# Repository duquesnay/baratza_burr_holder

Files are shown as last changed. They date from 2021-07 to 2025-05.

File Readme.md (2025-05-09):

# Baratza Encore Burr holder 3d model

3d Model for Baratza Encore burr holder - remixed from thingiverse: <https://www.thingiverse.com/thing:1731803>

## Thingiverse

Published based on : 

### Thingiverse Description

Baratza burr holder re-engineered from Michał Barczewski's version on thingiverse: <https://www.thingiverse.com/thing:4900741>

I've made some heavy handed changes
- redesigned some parts to be more fit to 3d printing & PETG, regarding strength overall and precision
- most noticeable are: a full on outer threading instead of small original tabs ; thicker rings on top for easier printing and sturdiness
- added a rugged outside for manual screwing/unscrewing when testing

Model available on: https://github.com/duquesnay/baratza_burr_holder.git

### Print notes
(GD After a bit of trail & error)
- PETG is the way. PLA is too hard and won't handle the friction of the outer threading for a part so thin. Everything is small and put together tight in the grinder so the flexibility is not getting in the way. Also, heat resistance is never bad, grinding creates heat
- 0.2 layer height needed to gives a smooth threading
- 0.43 layers width w 0.6 nozzle
- wall count of 3 w 0.6 nozzle, the part is mostly solid.
- no support: it never comes out clean from the outer thread, any bits add friction
- made to use straigt out of the printer 

## Code style notes
I've made a lot of refactoring from the original code, based on software coding experience
- went hard Clean Code principles to refactor the file: named most hard coded value as variables and modules renamed to express the function of the part. Should be easier to work on
- redesigned the shape hierarchy so each part is visualized independently (different colors)

## Design Notes
Recent updates:
- BOSL2 library integration for advanced features
- Printing upside down 
  - prevents support since the top part of the millstone, main point of pressure on it, is flat
  - had to extend external tabs -now a ring to the max height
- Outer thread
  - Replaced middle tab with thread_helix - smoother & stronger threads
  - Triple-start trapezoidal thread design - easy printing, easy sliding, but precise holding (since thread goes all the way around)
  - Thread params: 0.3 turns, 2mm pitch, 1.5mm depth (max is 2 but not more friction and printing issue, lead-in for easy engagement
- Top part
  - Replaces flimsy top tabs with full rings, going all the way up for support. Nothing else needed
  - There's a flat bridge between the upper rings but it prints easy at this dimension (2mm in circle)
- Bottom
  - cylinder segments is split by sections, to work on each feature independently
  - the tabs retaining the millstone have vertical slit for flexibility, there must be a stronger way, they might need a bit of care... but also do push it strongly 

 ## Todos
- [X] remove pointless cutouts on bottom top shoulder
- [X] remove useless shoulder between top and bottom
- [X] replace top tabs as a full ring for resistance and printing
- [X] thicken the stabiliser ridge to limit movement of the burr
- [X] fine-tuned the spacing between the rings for taking in the rubber part

## License
Attribution-NonCommercial-ShareAlike 4.0 International (CC BY-NC-SA 4.0) <https://creativecommons.org/licenses/by-nc-sa/4.0/>

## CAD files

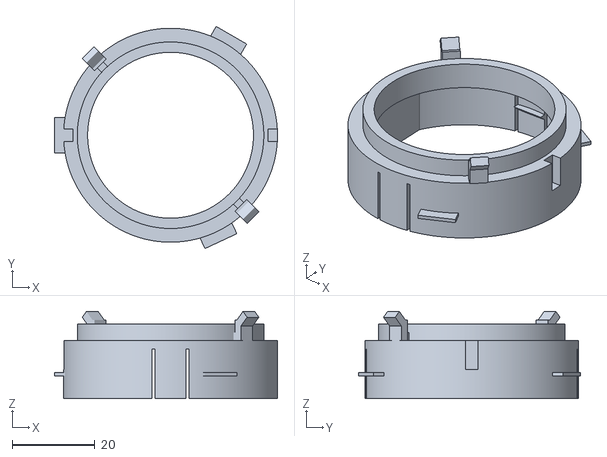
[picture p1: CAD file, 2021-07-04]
burrholder_v3.stl
53.8 x 53.6 x 21.0

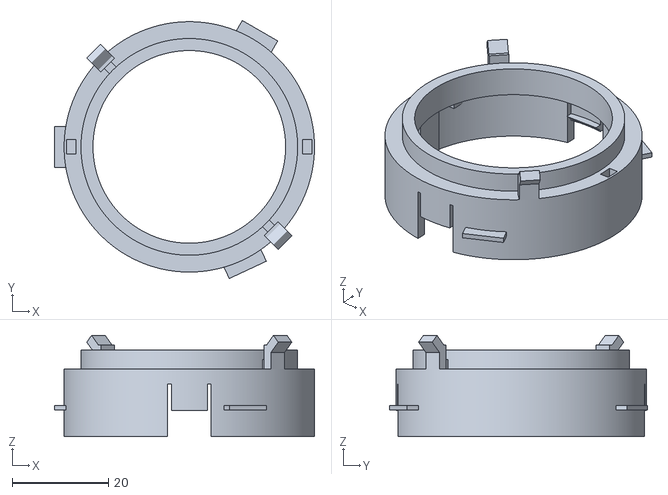
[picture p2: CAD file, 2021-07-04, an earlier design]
burrholder_v2.stl
54.0 x 53.6 x 21.0

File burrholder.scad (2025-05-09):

// Include BOSL2 library
include <BOSL2/std.scad>
include <BOSL2/threading.scad>

// Quality settings
$fa = 0.1;
$fs = 0.4;

// Dimensions - Main structure
outer_diameter = 51.6; // [51:0.05:53]
bottom_radius = outer_diameter / 2;
bottom_thickness = 1.7; // [1:0.1:2]
bottom_internal_radius = bottom_radius - bottom_thickness;


// Parameters for upper ring
top_ring1_outer_radius = 21;
top_ring1_inner_radius = 18;
top_rings_spacing = 2.5;    // Spacing between ring 1 and 2
top_ring2_outer_radius = bottom_radius + 2;


// Parameters for upper tabs
rubber_tab_width = 2;
rubber_tab_height = 3;  // Added to shoulder_height
rubber_tab_angles = [45, 225];  // Angles around the circle where tabs are placed

// Parameters for retainer tabs
retainer_tab_contenance = 4.5; // Millstone has a 4mm lip, so .5 margin

// Heights - Sections
top_rings_height = 5;
shoulder_height = 3;
bottom_height = 11;
shoulder_extension = 1.5;

// Tabs - Dimensions
side_holder_length = 1.2; // [1:0.1:2]

// https://en.wikibooks.org/wiki/OpenSCAD_User_Manual/Primitive_Solids
module prism(l, w, h) {
    polyhedron(
    points = [[0, 0, 0], [l, 0, 0], [l, w, 0], [0, w, 0], [0, w, h], [l, w, h]],
    faces = [[0, 1, 2, 3], [5, 4, 3, 2], [0, 4, 5, 1], [0, 3, 4], [5, 2, 1]]);
}


// Create a beveled cylinder - generic function
// h = height, or = outer radius, ir = inner radius, tb = top bevel width, bb = bottom bevel width
module beveled_tube(h, or, ir, tb = 0, bb = 0) {
    assert(or >= ir, "Inner radius must be less than outer radius");
    assert(h >= tb + bb, str("Height (", h, ") must be greater than top plus bottom bevels", [tb, bb]));
    echo("Beveled tube: ", [h, or, ir, tb, bb]);
    thickness = or - ir;
    if (tb > thickness) {
        tb = thickness;
    }
    if (bb > thickness) {
        bb = thickness;
    }
    union() {
        if (h > bb + tb)
            translate([0, 0, bb])
                tube(h = h - tb - bb, or = or, ir = ir, center = false);
        if (tb > 0)
            translate([0, 0, h - tb])
                tube(h = tb, or1 = or, or2 = or - tb, ir = ir, center = false);
        if (bb > 0) {
            tube(h = bb, or1 = or - bb, or2 = or, ir = ir, center = false);
        }
    }
}

// Stable tube/ring module using only core OpenSCAD functions
// Parameters:
// h = height of the tube
// or1 = outer radius at bottom
// or2 = outer radius at top (defaults to or1 if not specified)
// ir1 = inner radius at bottom
// ir2 = inner radius at top (defaults to ir1 if not specified)
// fn = optional fragment number (resolution)
module stable_tube(h, or1, ir1, or2 = undef, ir2 = undef, fn = $fn) {
    // Default values for optional parameters
    or2_actual = (or2 == undef) ? or1 : or2;
    ir2_actual = (ir2 == undef) ? ir1 : ir2;

    // Input validation
    assert(h > 0, str("Height must be positive: ", h));
    assert(or1 >= ir1, "Outer radius must be greater than inner radius at bottom");
    assert(or2_actual >= ir2_actual, "Outer radius must be greater than inner radius at top");

    // Create a 2D profile and rotate it around the Z axis
    rotate_extrude(angle = 360, $fn = fn) {
        polygon(
        points = [
                [ir1, 0], // Bottom inner
                [or1, 0], // Bottom outer
                [or2_actual, h], // Top outer
                [ir2_actual, h]    // Top inner
            ],
        // Define the face as a simple quad
        paths = [[0, 1, 2, 3]]
        );
    }
}

// Create the hollow top cylinder
module top_ring1(
outer_radius = top_ring1_outer_radius,
inner_radius = top_ring1_inner_radius,
height = top_rings_height
) {
    tube(h = height, or = outer_radius, ir = inner_radius, center = false);
}

// Create a continuous vertical ring around the top cylinder with connectors
module top_ring2(
height = top_rings_height,
base_spacing = top_rings_spacing, // should be refreing to connector origin
outer_radius = top_ring2_outer_radius  // Same as shoulder outer_radius default
) {
    inner_radius = base_spacing + top_ring1_outer_radius;
    thickness = outer_radius - inner_radius;
    outer_radius = outer_radius; // making it thicker to compensate
    bb = outer_radius - bottom_radius; // just in case we decide to over over large

    difference() {

        beveled_tube(
        h = height,
        or = outer_radius,
        ir = inner_radius,
        tb = 0,
        bb = bb
        );

        count = 8;
        for (i = [0:count - 1])
        rotate([0, 0, i * (360 / count)])
            translate([outer_radius + 4, 0, 0])
                cylinder(r = 6, h = height);

    }

}

// Create the shoulder transition part with reinforcement
// @todo to refactor, using common variables, etc
module shoulder(
height = shoulder_height,
inner_radius = top_ring1_inner_radius,
outer_radius = bottom_radius
) {
    bevel = top_rings_spacing;
    tube(h = height, or = outer_radius, ir = inner_radius, center = false);
}

// Parameters for middle tab thread
middle_tab_pitch = 2;
middle_tab_thread_width = 0.8;  // Make thread thinner (1mm in total width)
middle_tab_thread_depth = 2;    // Make thread thinner (1mm in total width)
middle_tab_turns = 0.3;
middle_tab_starts = 3;
middle_tab_lead_in = 2;
middle_tab_left_handed = true;
thread_depth = 1.5;      // Standard depth for reliable threading

// Middle tab with helix angle for threading onto the grinder
module tightening_thread() {
    // Use standard thread parameters that are known to work well

    // Use the default thread profile which renders reliably
    thread_helix(
    turns = middle_tab_turns, // Standard turns value
    d = (bottom_radius) * 2, // Outer diameter
    pitch = 2, // Distance between complete turns, fixed
    starts = 3, // Triple-start thread
    thread_depth = thread_depth, // how deep the thread goes, max 2 probably
//    thread_angle = 0, // Square thread profile for precision fit
    left_handed = true,
    lead_in1 = 2, // Standard lead-in
    anchor = BOTTOM
    );
}

// Create a segment of the hollow bottom cylinder
module bottom_cylinder_segment(
start_angle,
end_angle,
outer_radius = bottom_radius,
inner_radius = bottom_internal_radius,
height
) {
    angle_span = end_angle - start_angle;

    // Outer segment
    rotate([0, 0, start_angle])
        rotate_extrude(angle = angle_span)
            translate([inner_radius, 0, 0])
                square([outer_radius - inner_radius, height]);
}

// Create a holder segment with the millstone holder integrated
module millstone_holder_segment(
angle_width = 60, // Angular width of the segment
outer_radius = bottom_radius,
inner_radius = bottom_internal_radius,
height = bottom_height,
overlap_clearance = 0.05,
height_clearance = 0.1
) {
    // Calculate the start and end angles to center the holder at 0°
    half_width = angle_width / 2;
    start_angle = -half_width;
    end_angle = half_width;

    union() {
        // Create the cylinder segment
        bottom_cylinder_segment(
        start_angle = start_angle,
        end_angle = end_angle,
        outer_radius = outer_radius,
        inner_radius = inner_radius,
        height = height
        );

        millstone_single_holder();
    }
}

// Create a segment with millstone retaining tab and horizontal flexibility slots
module millstone_retainer_tab_segment(
angle_width,
height = bottom_height,
z_position = bottom_height - retainer_tab_contenance,
tab_width = 7.5,
tab_depth = 1.5,
outer_radius = bottom_radius,
inner_radius = bottom_internal_radius,
tab_length = side_holder_length,
slit_width = 1,
) {
    // Calculate the start and end angles to center the tab with a negative margin to create slits
    end_angle = angle_width / 2 - slit_width;
    start_angle = -end_angle;

    union() {
        // Create the complete cylinder segment
        bottom_cylinder_segment(
        start_angle = start_angle,
        end_angle = end_angle,
        height = height
        );

        // Add the millstone tab - rotated to align perpendicular to the cylinder radius
        // The -90° rotation positions the tab at right angles to the segment's central angle
        translate([inner_radius, 0, z_position])
            rotate([0, 0, 180])
                //            translate([ inner_radius, 0, z_position])
                retainer_tab(tab_width, tab_depth, tab_length);
    }
}

// Create a single millstone tab
module retainer_tab(
width,
depth,
height,
) {
    rotate([-90, 0, 0])
        linear_extrude(width, center = true)
            polygon(points = [[0, 0], [depth, 0], [0, height]]);
}
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

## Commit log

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2021-07-04 fix module name in debug
    [burrholder.scad]
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2021-07-04 fix top cutout to account for bigger diameter
    [burrholder.scad]
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2021-07-04 revert side holders
    [burrholder.scad]
2021-07-04 make side holders adjustable and shorten them
    [burrholder.scad]
2025-01-18 top cylinder now as high as the tabs
    [burrholder.scad]
2025-01-18 replacing top slanted tip by a bevel tip for top bed adhesion
    [burrholder.scad]
2025-01-18 refactor top tabs creation: - tab extending to top height to be printed upside down - clean code, more variables, etc
    [burrholder.scad]
2025-01-18 form changed: beveling middle shoulder for easier upside down print (to be tested)
    [burrholder.scad]
2025-01-18 refactored for adjustement - cylinders don't overlap - using bottom, shoulder, top, as reference name - upper tabs go down to the bottom as the shoulder will be tapered - ring stone holder made throu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
    [burrholder.scad]
2025-01-18 refactored for adjustement - stone holders refactored to use functions and parameters in place of hard values
    [burrholder.scad]
2025-01-18 made stone holder tabs tigher by half a millimeter
    [burrholder.scad]
2025-05-02 refactor: extract magic numbers into named variables for improved maintainability
    - Add descriptive variable names across all modules
    - Improve code readability with consistent naming
    - Add helpful comments describing purpose of sections
    - Use overlap_clearance consistently for 3D operations
    [burrholder.scad]
2025-05-02 refactor: standardize naming conventions throughout codebase
    - Use consistent suffix naming (_height, _width, _radius)
    - Rename variables for clarity (tab_mid_h → middle_tab_height)
    - Convert indexed loops to named angle arrays
    - Group related parameters with prefixes (holder_*)
    - Improve organization with section comments
    - Standardize parameter variable names across modules
    [burrholder.scad]
2025-05-02 feat: improve debugging visualization for cutouts
    - Enhance debug visualization to show all cutout types
    - Add colored visualization for retaining tabs (green) and top cutouts (yellow)
    - Extract cutout application into dedicated apply_cutouts module
    - Use array-based loop for slit cutouts rotation
    - Fix variable reference (bottom_h to bottom_height)
    - Add explanatory comments for better maintainability
    [burrholder.scad]
2025-05-02 fix: correct debugging visualization syntax errors
    - Fix typo in millstone_cutouts_slits function name
    - Correct condition check (was comparing to 0 instead of 1)
    - Enable debugging visualization by default
    - Uncomment debugging section
    [burrholder.scad]
2025-05-02 fix: correct all OpenSCAD for-loop syntax
    - Replace all instances of incorrect 'for (x in array)' syntax
    - Use proper OpenSCAD array iteration with indexing: 'for (i = [0:len(array)-1])'
    - Fix loop syntax in upper_tabs, middle_tabs, millstone_holders, apply_cutouts
    - Fix millstone_retainting_tab_cutouts loop syntax
    - Ensure consistent array access pattern across the entire file
    [burrholder.scad]
2025-05-02 refactor: use descriptive variable names in array iterations
    - Rename generic index variables (i) to descriptive names
    - Use tab_index for tab-related arrays (upper_tabs, middle_tabs)
    - Use side_index, slit_side for side-specific elements
    - Use position_index for positional arrays
    - Use holder_index for holder-related iterations
    - Improve debug visualization with array-based color assignment
    - Add helpful comments explaining index meanings
    - Fix missing closing bracket in debug visualization
    [burrholder.scad]
2025-05-02 refactor: simplify loops with direct iteration over values
    - Replace index-based iteration with direct value iteration
    - Remove unnecessary variable arrays and indexing
    - Use direct values in for loops: for (angle = [0, 180])
    - Use descriptive variable names (angle, y_position)
    - Remove redundant temporary arrays and calculations
    - Simplify debug visualization with direct approach
    - Fix indentation in debug visualization section
    - Remove unnecessary tab_positions_y array
    [burrholder.scad]
2025-05-02 refactor: make cutout positions perfectly symmetrical
    - Use consistent radius of 25 units for all cutouts
    - Add explicit tab_center_radius and tab_y_offset variables
    - Apply consistent 1.5 unit offset to both sides
    - Create matching variables for slit cutouts
    - Calculate positions instead of using hard-coded values
    - Improve comments explaining position calculations
    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
    [burrholder.scad]
2025-05-02 refactor: remove original cutout type in favor of slits
    - Remove cutout_type parameter and conditional logic
    - Delete millstone_retainting_tab_cutouts module (unused)
    - Simplify apply_cutouts module to only use slits
    - Remove retaining tab visualization from debug view
    - Clean up whitespace in debug visualization section
    - Fix indentation issues in debug section
    - Streamline configuration options section
    [burrholder.scad]
2025-05-04 refactor: extract millstone tab parameters to global scope
    [burrholder.scad]
2025-05-04 refactor: extract millstone slit parameters to global scope
    [burrholder.scad]
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2025-05-04 refactor: create consolidated function for all millstone slits
    [burrholder.scad]
2025-05-04 refactor: improve debug visualization with dynamic colors for slits
    [burrholder.scad]
2025-05-04 docs: add documentation module for millstone tab and slit system
    [burrholder.scad]
2025-05-04 feat: apply 2.2° thread angle to middle tabs for threading, wider tabs (14mm)
    [burrholder.scad]
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2025-05-05 Replace middle tab with BOSL2 thread_helix
    [burrholder.scad]
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2025-05-05 Refine thread profile with custom asymmetric shape
    - Implement specialized buttress-like thread profile
    - Add external ridge and shoulder features
    - Increase thread depth to 2mm for stronger engagement
    - Optimize thread geometry for better load distribution
    - Refactor top_cutouts module to use angle array
    [burrholder.scad]
2025-05-05 Remove top shoulder cutouts
    - Disable top_cutouts in apply_cutouts function
    - Mark related todo item as completed in documentation
    - Simplifies model and improves structural integrity
    [burrholder.scad]
2025-05-05 refactor: encapsulate parameters within their respective modules
    - Extract and internalize parameters for each component module
    - Improve module interfaces with explicit parameters and defaults
    - Maintain backward compatibility with legacy functions
    - Fix debug visualization to use correct angle values
    - Update documentation comments for clarity
    [burrholder.scad]
2025-05-05 refactor: introduce bottom_cylinder_segment module
    - Add bottom_cylinder_segment module for creating angular cylinder segments
    - Refactor bottom_cylinder to use a 360° segment
    - Keep exact same behavior and appearance
    - Prepare for future incremental segmentation
    This is the first step toward vertical segmentation of the cylinder,
    which will later allow for specialized sections.
    [burrholder.scad]
2025-05-05 refactor: integrate 0° holder into dedicated segment
    - Create zero_degree_holder_segment module for 0° position
    - Split base cylinder into specialized segment and plain segment
    - Handle angle wraparound by creating two partial segments
    - Update millstone_holders to skip the 0° holder
    - Update millstone_retaining_tabs to skip the 0° tab
    - Fix color rendering for segments and cylinder parts
    This is the second step in vertical segmentation, integrating
    the holder, tab, and slits for the 0° position into a dedicated
    segment of the cylinder.
    [burrholder.scad]
2025-05-05 major refactor: bottom cylinder broken down into the holder tab parts and plain walls
    [burrholder.scad]
2025-05-05 refactor: implement parametric segment spacing for millstone tabs and slits
    - Replace boolean difference operations with parametric spacing between segments
    - Move segment width parameters to variables for better organization
    - Calculate wall segment angles dynamically based on tab and holder widths
    - Improve angle calculations for proper segment spacing
    [burrholder.scad]
2025-05-05 refactor: clean code improvements for clarity
    - Add better comments for rotation mechanics in millstone_retainer_tab_segment
    - Rename deactivated_millstone_slit_at_angle to legacy_millstone_slit_at_angle for clarity
    - Improve parameter organization and documentation in bottom_parts module
    - Remove unnecessary nested union() in tab segment module
    [burrholder.scad]
2025-05-05 simplify: create straight upper tab design
    - Remove angled tab design in favor of straight vertical tab
    - Remove unused angle-related parameters
    - Simplify tab creation module
    [burrholder.scad]
2025-05-05 simplify: remove shoulder reinforcement
    - Remove reverse thicker reinforcement with bevel from shoulder transition
    - Clean up commented out code
    - Adjust parameter defaults for better consistency
    [burrholder.scad]
2025-05-05 simplify: replace upper tabs with continuous ring
    [burrholder.scad]
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2025-05-05 feat: add connectors to upper_ring using existing tab positions
    [burrholder.scad]
2025-05-05 fix: preserve original connector height in upper_ring
    [burrholder.scad]
2025-05-05 feat: align upper_ring width with shoulder outer radius
    [burrholder.scad]
2025-05-05 Fix thread rendering issues by using standard thread parameters
    [burrholder.scad]
2025-05-05 Fix thread rendering by using trapezoid profile for upper bevel
    [burrholder.scad]
2025-05-05 Implement improved thread profile and horizontal slots for better printing
    - Create asymmetric thread profile with 15° leading edge for precision
    - Replace vertical slits with horizontal slots for better layer strength
    - Simplify and improve segment organization in bottom cylinder
    - Fix wall segment positioning for proper geometry
    [burrholder.scad]
2025-05-05 Improve burrholder design for durability and printability
    - Add beveled transitions to upper ring to eliminate stress points
    - Replace vertical slits in retainer tabs with horizontal slots for layer strength
    - Invert shoulder transition cone for better load distribution
    - Optimize middle threading with standard trapezoidal profile for reliable engagement
    - Reorganize bottom cylinder segments with continuous walls for integrity
    [burrholder.scad]
2025-05-05 Implement simpler horizontal slots for tab flexibility
    - Replace complex slot generation with straightforward approach
    - Add two strategic slots above and below the retaining tabs
    - Position slots at 2mm offset from tab for optimal flexibility
    - Size slots proportional to segment width for better balance of strength and flexibility
    [burrholder.scad]
2025-05-09 (fix) re-established vertical slit (refactor) retainer tab segment recreated from scrach, compact, clean
    [burrholder.scad]
2025-05-09 (wip) refactor of top part in progress - renamed into top ring1, ring 2 - body describe each piece for now - ring1, 2 works - shoulder broken
    [burrholder.scad]
2025-05-09 (wip) refactor of top part in progress - using simpe tube and creating bevel_tube for upper rings - making ring 2 auto adjusted to bottom - shoulder not beveled, tbd - connectord for ring 1 & 2 broken
    [burrholder.scad]
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2025-05-09 (feat) restructured shoulder area - shoulder is its own layer - in between rings, with connector and eventual bevel its own thing too - need code cleaning at the shoulder area
    [burrholder.scad]
2025-05-09 (feat) return to a classic trapeze thread profile (square too hard to slide) (refactor) unused code cleanup
    [burrholder.scad]
2025-05-09 (feat) garanteed starting height of the thread - anchoring the thread_helix to BOTTOM
    [burrholder.scad]
2025-05-09 (fix) correcting retainer tabs (orientation, height)
    [burrholder.scad]
2025-05-09 (fix) enlarging top ring spacing for easier rubber part sliding
    [burrholder.scad]
